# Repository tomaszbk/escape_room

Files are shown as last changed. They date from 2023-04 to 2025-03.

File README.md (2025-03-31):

# Making my own Escape Room 🚪🗝️
### 📌 Summary:
Transformed my bedroom into an escape room! Combining electronics knowledge with programming, I designed and then put into action an experience 
made possible by the communication between the components and the Game Master's terminal dashboard

### 🖥️ Requirements:
**Hardware**:
- Arduino UNO
- ESP32
- LEDs
- buzzer
- lcd 16x2 display
- Shift register
- 4 Digit 7 Segment LED Display
- 4x4 matrix keypad
- Rfid reader and card
- 9v Battery

**Software**:
- C++
- Node-Red
- Mosquitto
- PlatformIo

### 🏆 Main challenges Overcomed
 - Setting up and syncing the inter-device data communications (Serial and MQTT).</li>
 - Setting the room's full status control and debug log for a Game Master</li>
 - Developing the respective board's codes in a fully modulized way, making code easy to reuse in the future.
 
## Fritzing diagrams:
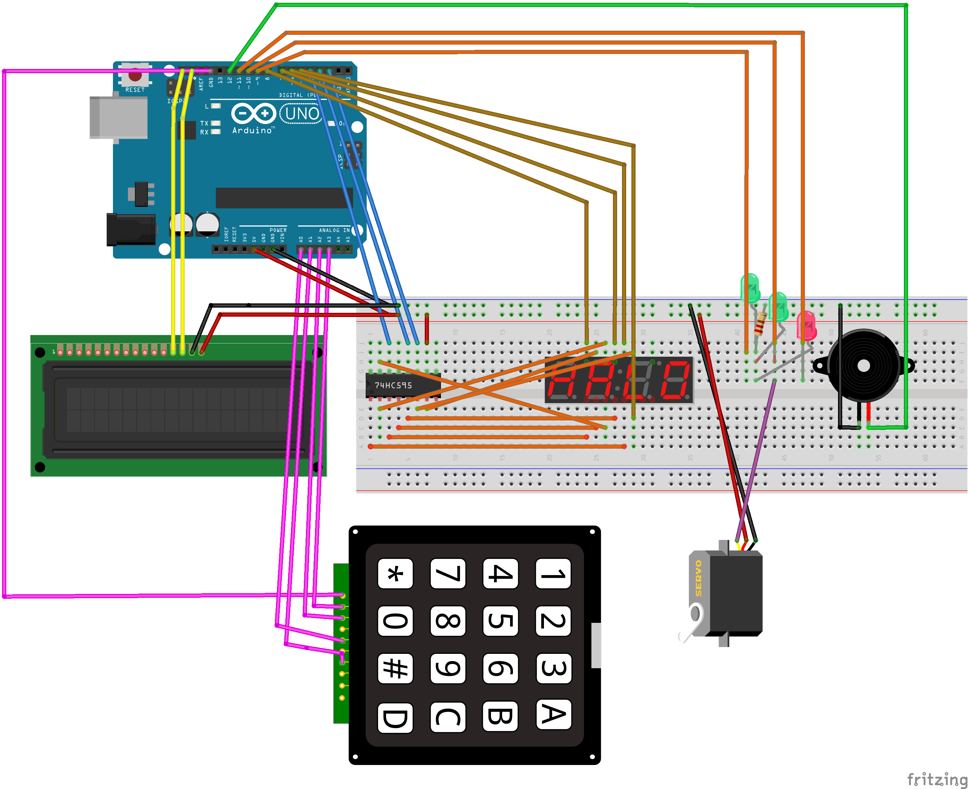
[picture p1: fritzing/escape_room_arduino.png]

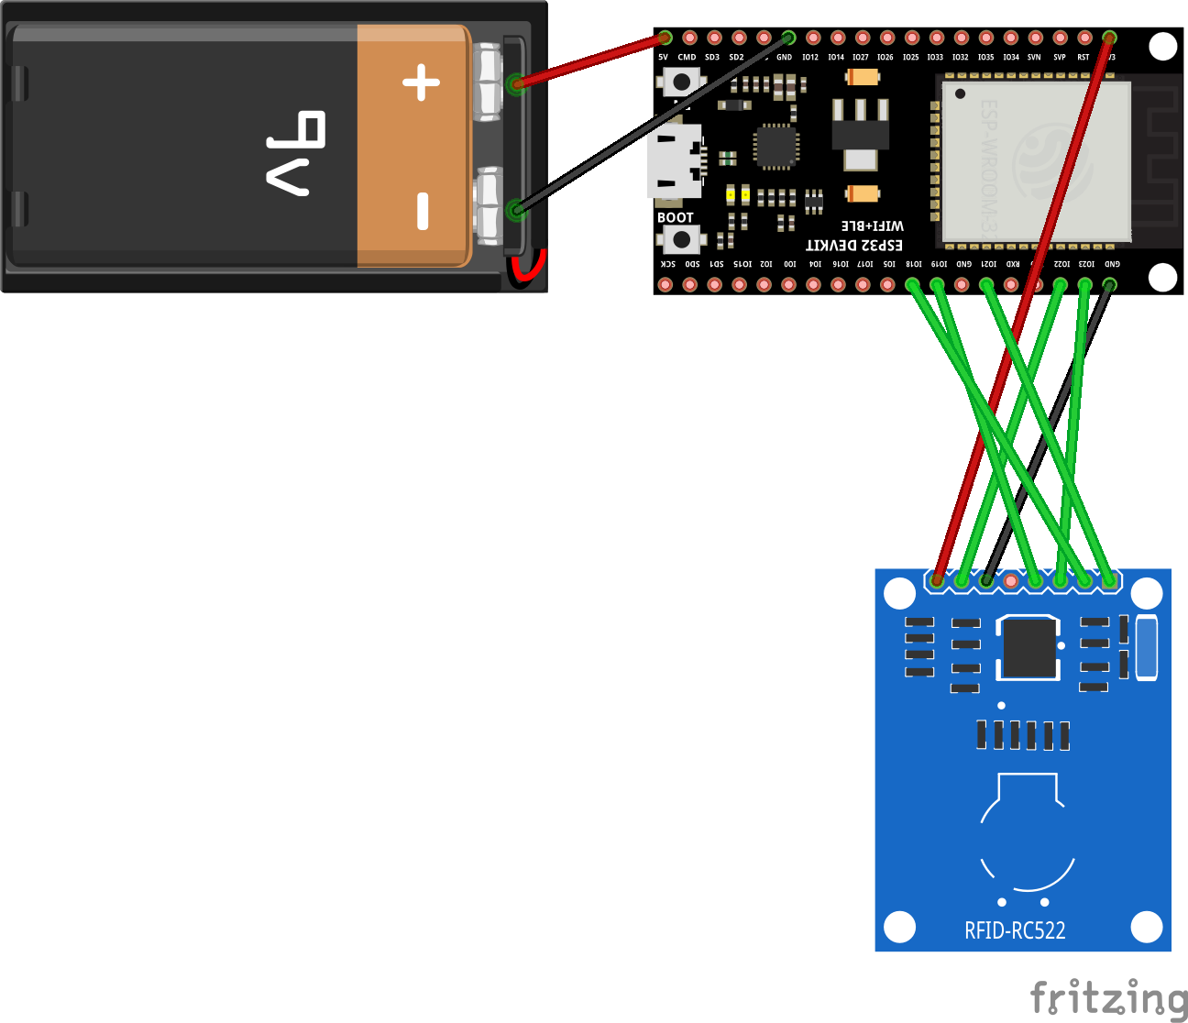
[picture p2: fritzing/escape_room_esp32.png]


## Node-red screenshot:
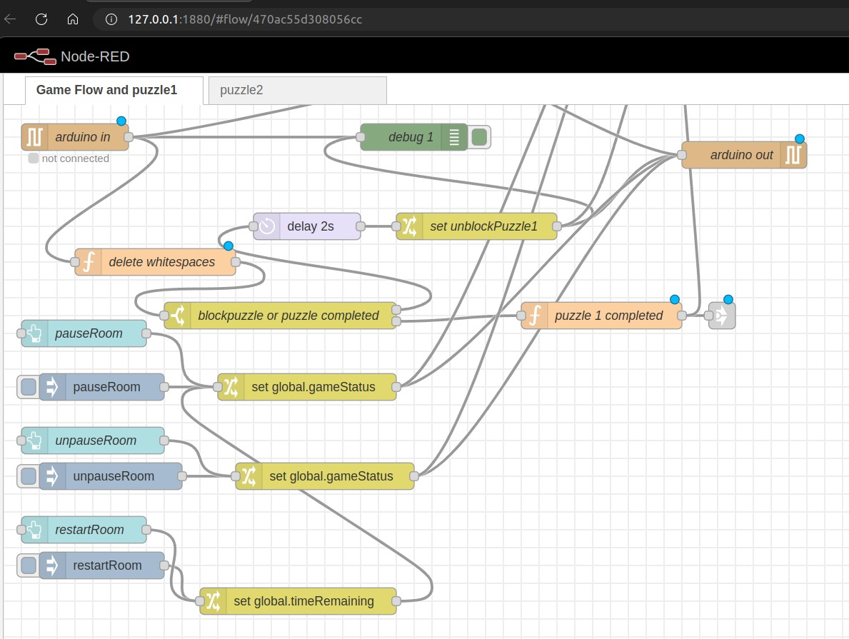
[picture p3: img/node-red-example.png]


## Gamemaster's Dashboard:
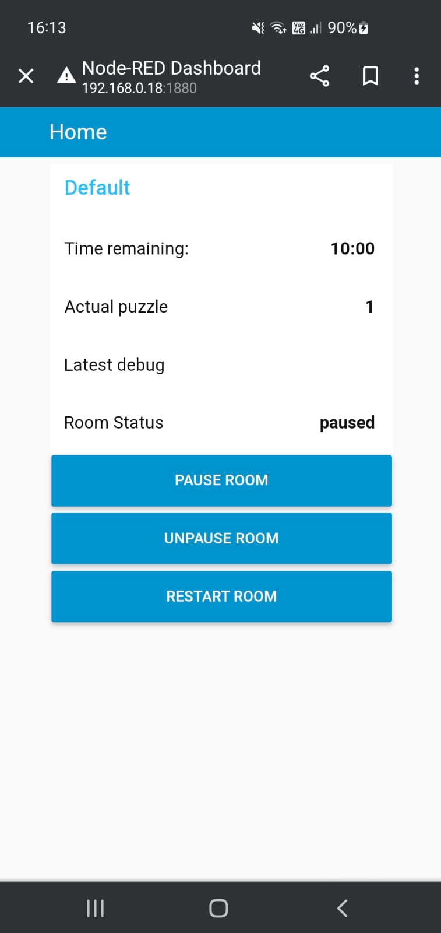
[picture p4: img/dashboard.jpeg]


<!-- ## Escape Room Demonstration 🔎
https://user-images.githubusercontent.com/85851175/235522523-4b475099-6c93-435e-834e-76cc130d574e.mp4 -->

The Room's first puzzle involves finding a code and inserting it in the 4x4 keypad.  
The second puzzle is solved placing an RFID card on a specific book (which has a hidden RFID reader).  
Afterwards, a Servo opens a box where the key to open the exit door is located.  
(Clues where hidden across my room, and are not shown for privacy reasons)

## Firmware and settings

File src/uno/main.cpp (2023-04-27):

#include <Arduino.h>
#include "Buzzer.h"
#include "Timer.h"
#include "Led.h"
#include "Display.h"
#include "Teclado.h"
#include "Servom.h"


char codigo[6] = {'3','1','5','4','6','2'};
char intento[6] = {'0','0','0','0','0','0'};

int8_t codigo_counter = 0;
int8_t puzzle1IsCorrect = 1; // 0 is False, 1 is True
int8_t puzzle_actual = 1;
int8_t isPaused = 1;

void puzzle1Completed();
void puzzle2Completed();
void blockPuzzle1();
void unblockPuzzle1();
String leerMensaje();
void unpauseRoom();
void pauseRoom();
void restartRoom();

void setup() {
  Serial.begin(19200);
  Serial.println("empieza setup");
  setupDisplay();
  setupTimer();
  resetServo();
  setupLed();
  setupBuzzer();
  Serial.println("termina setup");
  delay(1200);
}

void loop() {

  //SERIAL COMMUNICATIONS
  if (Serial.available()){
    delay(10);
    String mensaje = leerMensaje();
    Serial.println(mensaje);
    if (mensaje == "unblockPuzzle1"){
      unblockPuzzle1();
    }else if (mensaje =="unpauseRoom"){
      unpauseRoom();
    }
    else if (mensaje=="pauseRoom"){
      pauseRoom();
    }else if (mensaje=="restartRoom"){
      restartRoom();
    }else if (mensaje=="puzzle2Completed"){ 
      puzzle2Completed();
    } 
  }

  updateTimer();

  if (!isPaused){

    if(puzzle_actual == 1){
      char key = getKey();
      if(key != '0'){
        intento[codigo_counter] = key;
        if(codigo[codigo_counter] != key){
          puzzle1IsCorrect = 0; //si un intento esta mal, no es correcto
        }
        if (codigo_counter == 5){

          Serial.print("intento: ");
          Serial.println((char*)intento);

          if (puzzle1IsCorrect){
            puzzle1Completed();
          }else{
            blockPuzzle1();
          }
        }else{
          codigo_counter++;
        }
      }

    }else if (puzzle_actual == 2)
    {
      /* code */
    }
  }
}



void puzzle1Completed(){
  correctSound();
  puzzle_actual++;
  ledOneOn();
  displayPuzzle2();
  Serial.println("puzzle1Completed");
}

void puzzle2Completed(){
  correctSound();
  writeServo180();
  ledTwoOn();
  displayFinalPuzzle();
  pauseRoom();
}

void blockPuzzle1(){
  ledWrongOn();
  puzzle_actual = -1;
  Serial.println("blockPuzzle1");
  incorrectSound();
  codigo_counter = 0;
  puzzle1IsCorrect=1;
}
void unblockPuzzle1(){
  ledWrongOff();
  puzzle_actual = 1;
}

String leerMensaje(){
  char caracter;
  String mensaje = "";
  caracter = Serial.read();
  while (caracter != '\n'){
    mensaje += caracter;
    caracter = Serial.read();
  }
  return mensaje;
} 

void unpauseRoom(){
  isPaused = 0;
}
void pauseRoom(){
  isPaused = 1;
}
void restartRoom(){
  puzzle_actual = 1;
  isPaused = 1;
  codigo_counter =0;
  puzzle1IsCorrect = 1;
  ledsOff();
  resetTimer();
  resetServo();
  setupDisplay();
}

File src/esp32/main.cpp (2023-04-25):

#include <Arduino.h>
#include <WiFi.h>
#include <PubSubClient.h>
#include "Rfid.h"

const char* ssid = "Vora 2.4G";
const char* password = "tomate0001";
const char* mqttServer = "192.168.0.18";
const int mqttPort = 1883;
const char* mqttUser = "tomas";
const char* mqttPassword = "escape";
int8_t activated = 0;


WiFiClient espClient;
PubSubClient client(espClient);

void callback(char* topic, byte* payload, unsigned int length);
void activatePuzzle2();
void deactivatePuzzle2();
void puzzle2Completed();
void reconnect();

void setup()
{
    // Serial.begin(9600);
    rfidSetup();
    WiFi.begin(ssid, password);
    // Serial.print("Esp32 Connecting to WiFi.");
    while (WiFi.status() != WL_CONNECTED){
        delay(500);
    }
    //Serial.println("Wifi Connected");

    client.setServer(mqttServer, mqttPort);
    client.setCallback(callback);

    while (!client.connected()){
        //Serial.println("Connecting to MQTT...");
        if (client.connect("ESP32Client",mqttUser,mqttPassword)){
            //Serial.println("connected");
            client.subscribe("esp32");
            client.publish("debug", "esp32 conectado");
        }else{
            //Serial.print("failed");
            delay(1500);
        }
    }
}

void loop()
{
    if (! client.connected()){
        reconnect();
    }
    client.loop();
    if (activated == 1){    
        if (checkRfid()){
            client.publish("debug","se procede a llamar puzzle2Completed");
            puzzle2Completed();
        }
    }
}

void callback(char* topic, byte* payload, unsigned int length) {
    // String payloadStr = "";
    // for (int i = 0; i < length; i++) {
    //     payloadStr += (char)payload[i];
    // }
    // Serial.print("mensaje String payloadStr es: ");
    // Serial.println(payloadStr);

    char msg[length];
    memcpy(msg,payload,length);
    msg[length]='\0';

    // client.publish("fromDevice/debug", "esp32 llego mensaje");
    // client.publish("fromDevice/debug","2: ");
    // client.publish("fromDevice/debug", payloadStr.c_str());

    if (strcmp(msg,"activatePuzzle2") == 0){
        activatePuzzle2();
    }else if (strcmp(msg,"deactivatePuzzle2") == 0){
        deactivatePuzzle2();
    }
}

void activatePuzzle2(){
    activated=1;
    client.publish("debug","puzzle 2 activado");
}
void deactivatePuzzle2(){
    activated=0;
    client.publish("debug","puzzle 2 desactivado");
}

void puzzle2Completed(){
    client.publish("esp32","puzzle2Completed");
    activated=0;
}


void reconnect(){
  while (!client.connected()) {
    //Serial.print("Attempting MQTT connection...");
    if (client.connect("ESP32Client",mqttUser,mqttPassword)){
        client.subscribe("esp32");
        client.publish("debug", "esp32 reconectado");
    } else {
        //Serial.print("failed");
        delay(1000);
    }
  }
}

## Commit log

2023-04-18 esp32 branch?
2023-04-23 fixed string comparison with payload
    [main.cpp, rfid2.cpp]
2023-04-24 serial puzzle2completed and servo
2023-04-24 problems with mqtt payload
    [main.cpp, rfid.cpp]
2023-04-25 fixed restart room not unblocking puzzle 1
    [main.cpp]
2023-04-27 added fritzing diagrams
    [escape_room_arduino.fzz, escape_room_esp32.fzz]
2023-05-01 added img and node red flow
